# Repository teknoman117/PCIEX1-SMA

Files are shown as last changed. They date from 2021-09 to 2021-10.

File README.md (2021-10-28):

# PCIEX1-SMA

Adapts a PCIe x1 slot into 6 SMA connectors (REFCLK, TX, and RX differential pairs), and a pin header for SMBUS and the PERST signal. This is intended to be the one of the lowest cost SMA adapter boards for PCIe x1.

Imagined use case is adapting the Crosslink-NX Evaluation Board into a PCIe capable board by installing the missing SMA connectors and providing an adapter board to an actual PCIe connector.

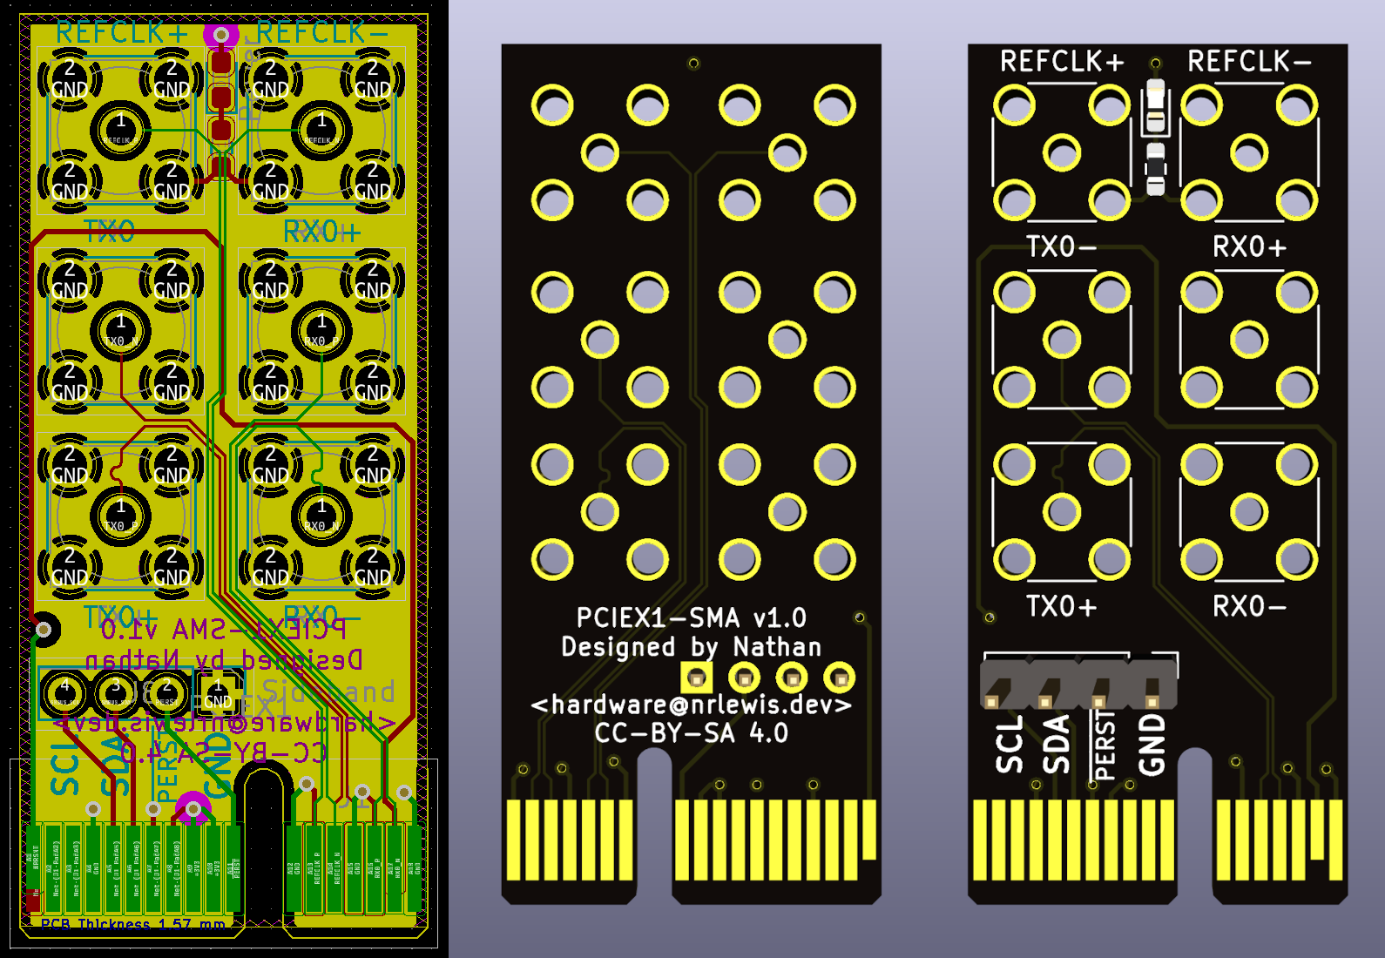
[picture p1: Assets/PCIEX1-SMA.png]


## License

CC-BY-SA 4.0

## Assembled
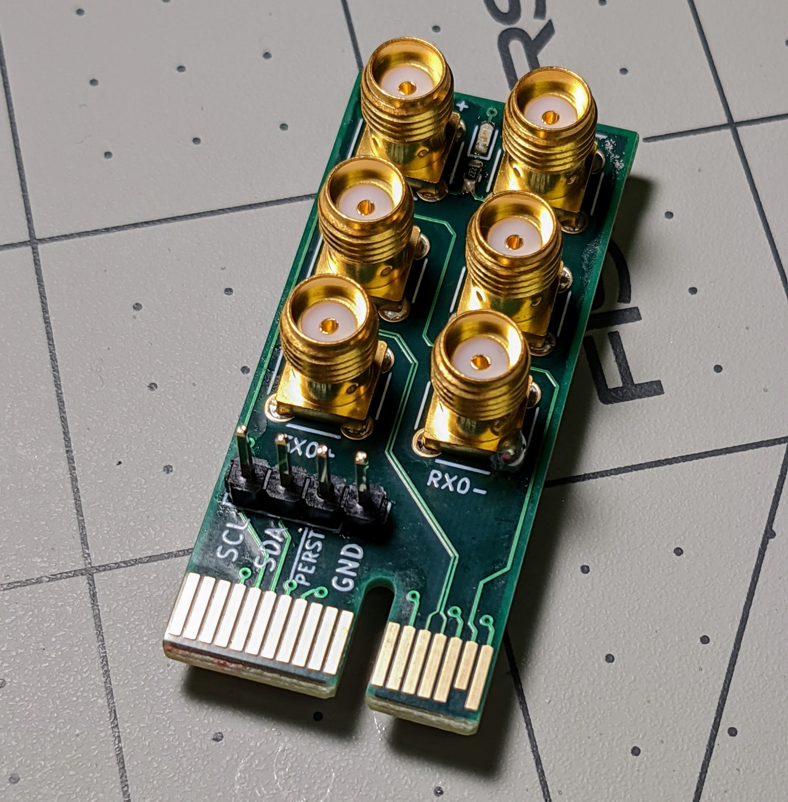
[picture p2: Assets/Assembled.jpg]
Assembled

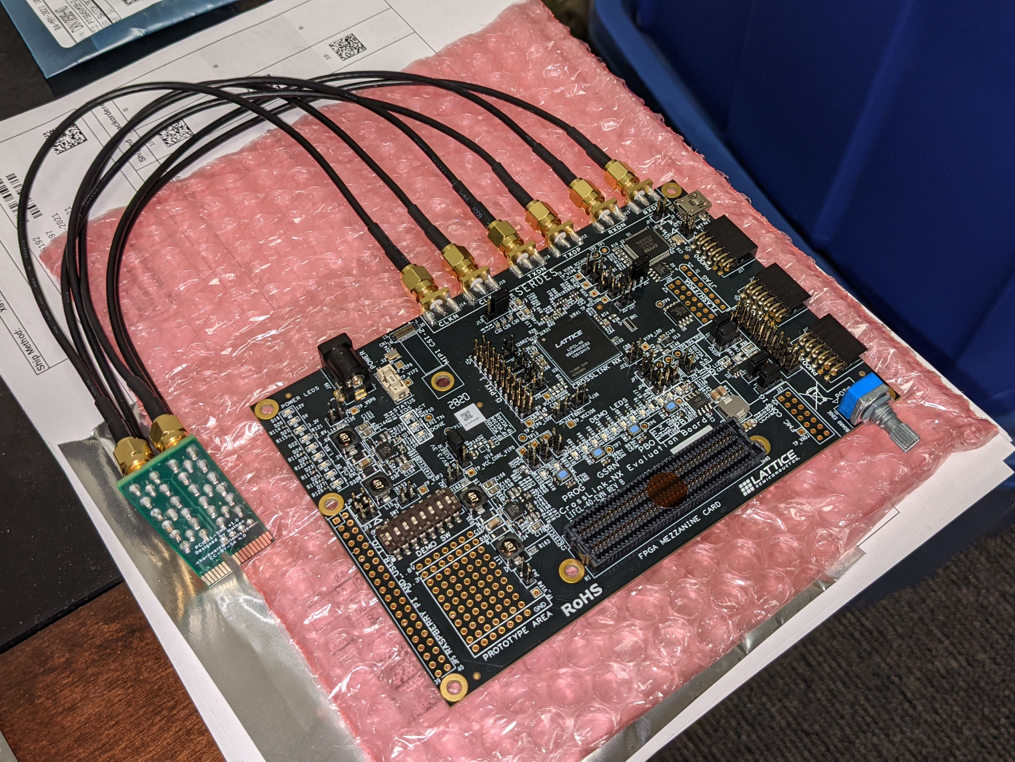
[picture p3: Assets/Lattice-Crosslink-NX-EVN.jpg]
FPGA

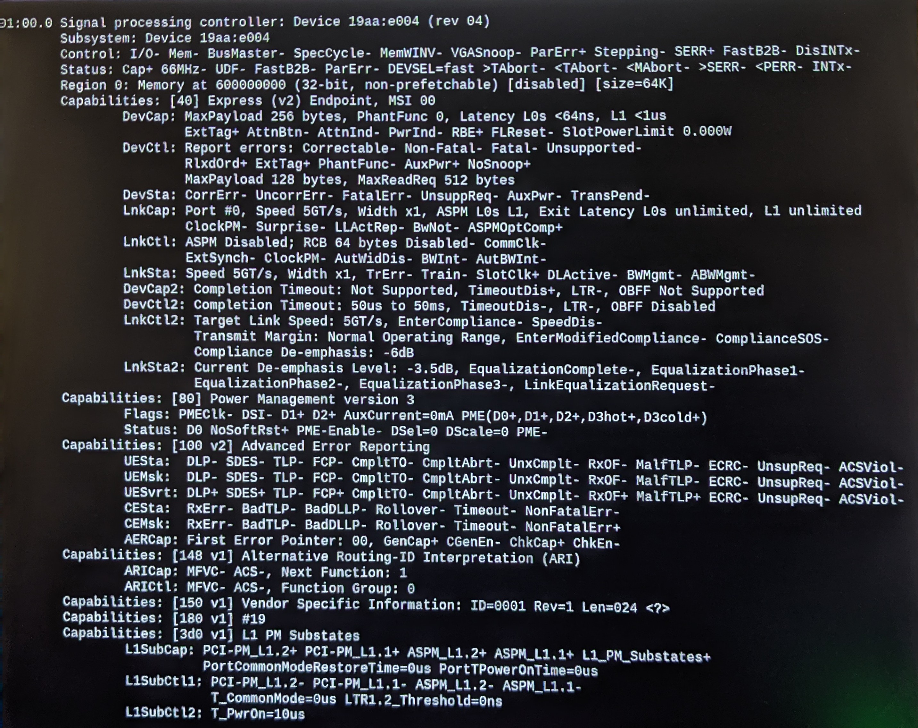
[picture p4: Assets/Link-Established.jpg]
Linkup


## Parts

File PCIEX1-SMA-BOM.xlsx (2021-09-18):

Reference | Quantity | Value | Footprint | Datasheet | Mouser_Link | Mouser_PN
D1 | 1 | Power | LED_SMD:LED_0603_1608Metric_Pad1.05x0.95mm_HandSolder | https://www.mouser.com/datasheet/2/180/IN-S63BT%20Series_V1.0-1115643.pdf | https://www.mouser.com/ProductDetail/Inolux/IN-S63BTR | 743-S63BTR
J2 J3 J4 J5 J6 J7 | 1 | (various) | Connector_Coaxial:SMA_Amphenol_132134_Vertical | https://www.mouser.com/datasheet/2/276/1/0733910060_RF_COAX_CONNECTORS-173237.pdf | https://www.mouser.com/ProductDetail/538-73391-0060 | 538-73391-0060
J8 | 1 | Sideband | Connector_PinHeader_2.54mm:PinHeader_1x04_P2.54mm_Vertical | https://www.mouser.com/datasheet/2/276/0423752523_PCB_HEADERS-700330.pdf | https://www.mouser.com/ProductDetail/Molex/42375-2523?qs=ZGcr3cVYdJBUbhMfSV37FA%3D%3D | 538-42375-2523
R1 | 1 | 2K2 | Resistor_SMD:R_0603_1608Metric_Pad0.98x0.95mm_HandSolder | https://www.mouser.com/datasheet/2/54/crxxxxx-1858361.pdf | https://www.mouser.com/ProductDetail/Bourns/CR0603-FX-2201ELF | 652-CR0603FX-2201ELF

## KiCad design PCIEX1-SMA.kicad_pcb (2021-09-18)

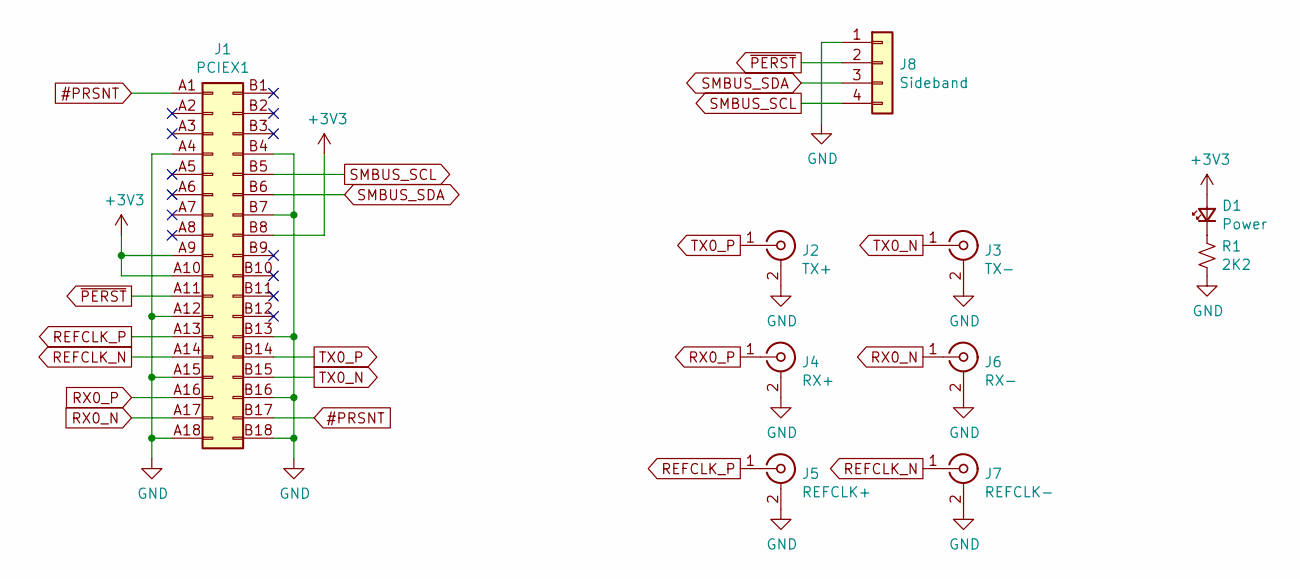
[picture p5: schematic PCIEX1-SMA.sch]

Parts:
D1: Power; LED_0603_1608Metric_Pad1.05x0.95mm_HandSolder; Mouser_PN 743-S63BTR
J1: PCIEX1; BUS_PCIexpress_x1
J2: TX+; SMA_Amphenol_132134_Vertical; Mouser_PN 538-73391-0060
J3: TX-; SMA_Amphenol_132134_Vertical
J4: RX+; SMA_Amphenol_132134_Vertical
J5: REFCLK+; SMA_Amphenol_132134_Vertical
J6: RX-; SMA_Amphenol_132134_Vertical
J7: REFCLK-; SMA_Amphenol_132134_Vertical
J8: Sideband; PinHeader_1x04_P2.54mm_Vertical; Mouser_PN 538-42375-2523
R1: 2K2; R_0603_1608Metric_Pad0.98x0.95mm_HandSolder; Mouser_PN 652-CR0603FX-2201ELF

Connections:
#PRSNT: J1.A1 (Pin_a1), J1.B17 (Pin_b17)
+3V3: D1.2 (A), J1.A9 (Pin_a9), J1.A10 (Pin_a10), J1.B8 (Pin_b8)
GND: J1.A4 (Pin_a4), J1.A12 (Pin_a12), J1.A15 (Pin_a15), J1.A18 (Pin_a18), J1.B4 (Pin_b4), J1.B7 (Pin_b7), J1.B13 (Pin_b13), J1.B16 (Pin_b16), J1.B18 (Pin_b18), J2.2 (Ext), J3.2 (Ext), J4.2 (Ext), J5.2 (Ext), J6.2 (Ext), J7.2 (Ext), J8.1, R1.2
unnamed: D1.1 (K), R1.1
REFCLK_N: J1.A14 (Pin_a14), J7.1 (In)
REFCLK_P: J1.A13 (Pin_a13), J5.1 (In)
RX0_N: J1.A17 (Pin_a17), J6.1 (In)
RX0_P: J1.A16 (Pin_a16), J4.1 (In)
SMBUS_SCL: J1.B5 (Pin_b5), J8.4
SMBUS_SDA: J1.B6 (Pin_b6), J8.3
TX0_N: J1.B15 (Pin_b15), J3.1 (In)
TX0_P: J1.B14 (Pin_b14), J2.1 (In)
~PERST: J1.A11 (Pin_a11), J8.2

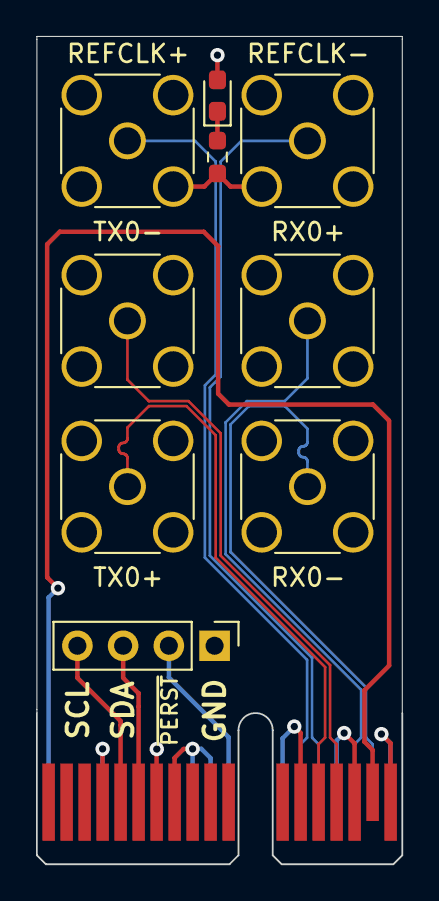
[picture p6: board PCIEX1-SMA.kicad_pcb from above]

Board: 4 copper layers, 20.3 x 46.0 mm, 10 parts (0 on the bottom side), 13 nets.

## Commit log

2021-09-18 first commit, state at manufacturing
    [PCIEX1-SMA-BOM.xlsx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]
2021-10-04 add assembled pictures
